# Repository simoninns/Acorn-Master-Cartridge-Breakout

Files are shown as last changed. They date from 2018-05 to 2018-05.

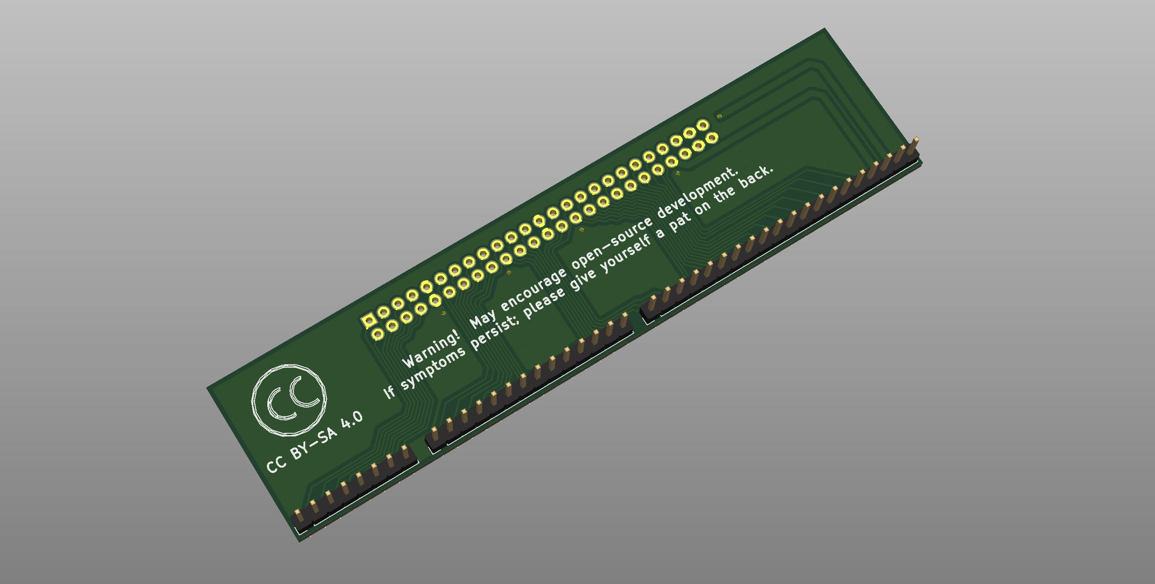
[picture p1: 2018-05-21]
Breadboard/Breadboard Header - bottom.jpg

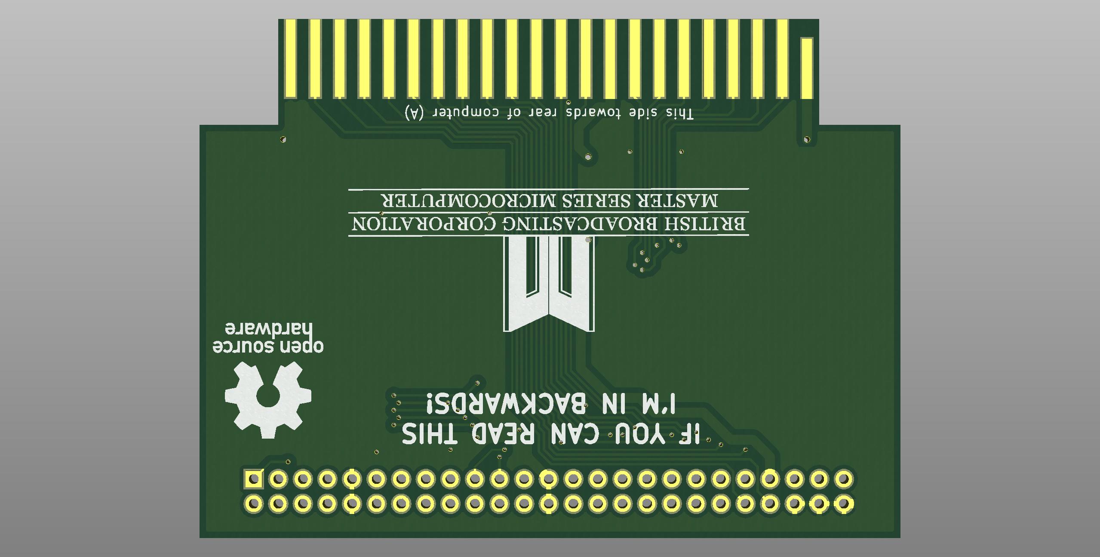
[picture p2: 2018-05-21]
Cartridge/Cartridge Header - bottom.jpg

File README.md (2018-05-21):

# Acorn-Master-Cartridge-Breakout
A breakout adapter for the Acorn Master 128 cartridge interface for connection to a breadboard

## Synopsis

This card is designed to allow connection between an Acorn BBC Master's cartridge interface and an electronics breadboard.  To save production cost the board is designed as two PCBs.  The cartridge header should be produced with a gold finish due to the edge connector (this is not required for the breadboard header).

## Motivation

Prototyping new Acorn BBC Master hardware.

## Author

The Acorn Master Cartridge Breakout board was designed by Simon Inns.

## License

This project is released under a Creative Commons Attribution-ShareAlike 4.0 International (CC BY-SA 4.0) licence.

You are free to:

Share — copy and redistribute the material in any medium or format
Adapt — remix, transform, and build upon the material
for any purpose, even commercially.

This license is acceptable for Free Cultural Works.

The licensor cannot revoke these freedoms as long as you follow the license terms.

Under the following terms:

Attribution — You must give appropriate credit, provide a link to the license,
and indicate if changes were made. You may do so in any reasonable manner, but
not in any way that suggests the licensor endorses you or your use.

ShareAlike — If you remix, transform, or build upon the material, you must
distribute your contributions under the same license as the original.

No additional restrictions — You may not apply legal terms or technological
measures that legally restrict others from doing anything the license permits.

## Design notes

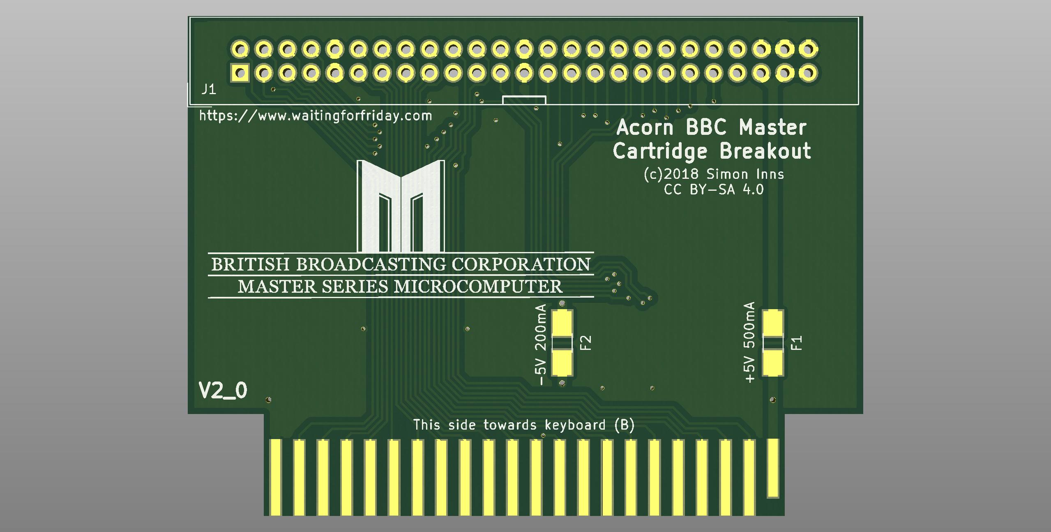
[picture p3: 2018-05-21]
Cartridge/Cartridge Header - top.jpg

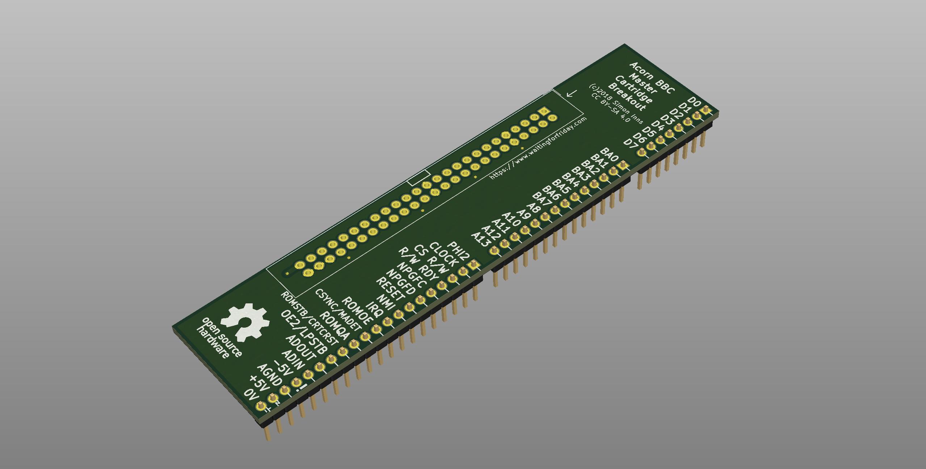
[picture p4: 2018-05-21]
Breadboard/Breadboard Header - top.jpg

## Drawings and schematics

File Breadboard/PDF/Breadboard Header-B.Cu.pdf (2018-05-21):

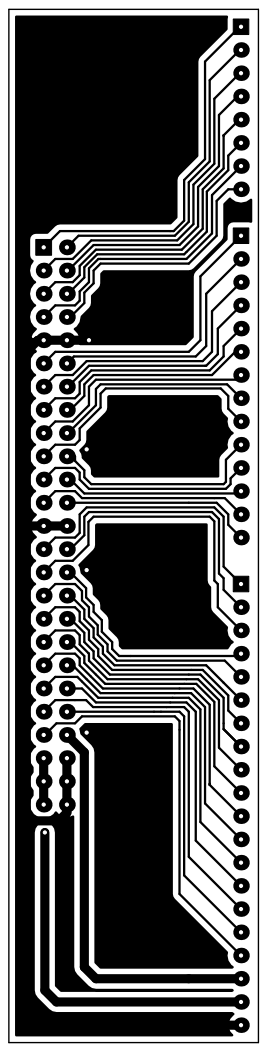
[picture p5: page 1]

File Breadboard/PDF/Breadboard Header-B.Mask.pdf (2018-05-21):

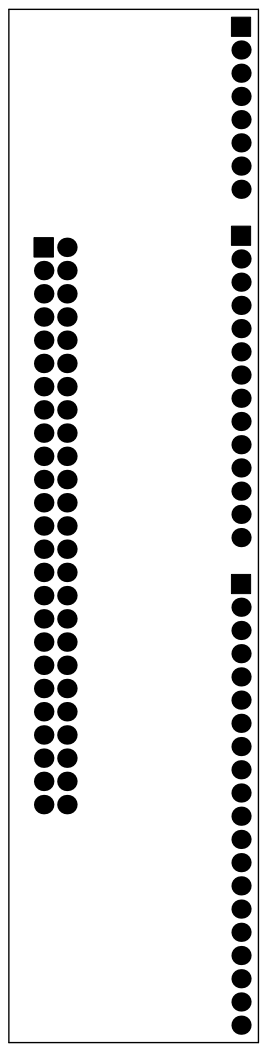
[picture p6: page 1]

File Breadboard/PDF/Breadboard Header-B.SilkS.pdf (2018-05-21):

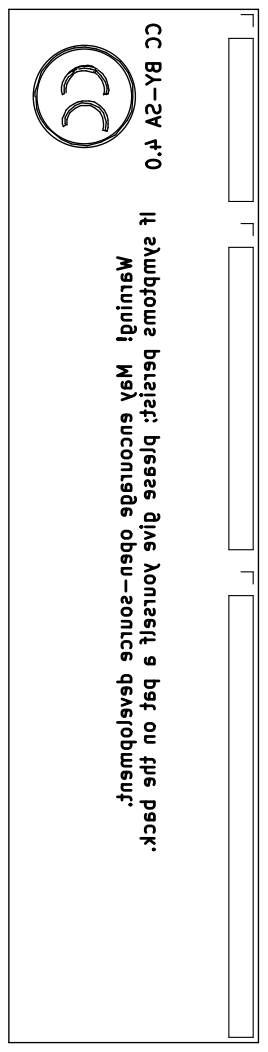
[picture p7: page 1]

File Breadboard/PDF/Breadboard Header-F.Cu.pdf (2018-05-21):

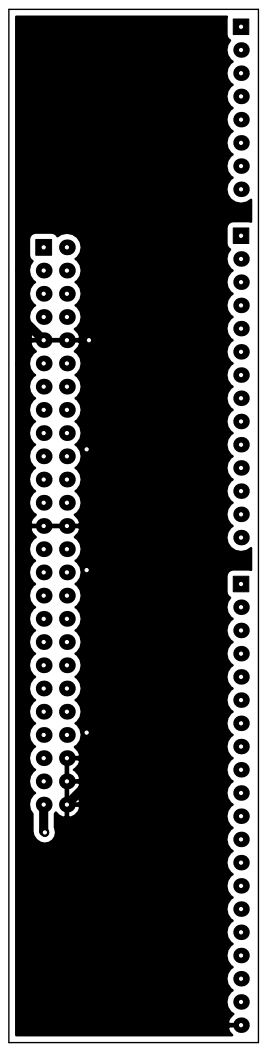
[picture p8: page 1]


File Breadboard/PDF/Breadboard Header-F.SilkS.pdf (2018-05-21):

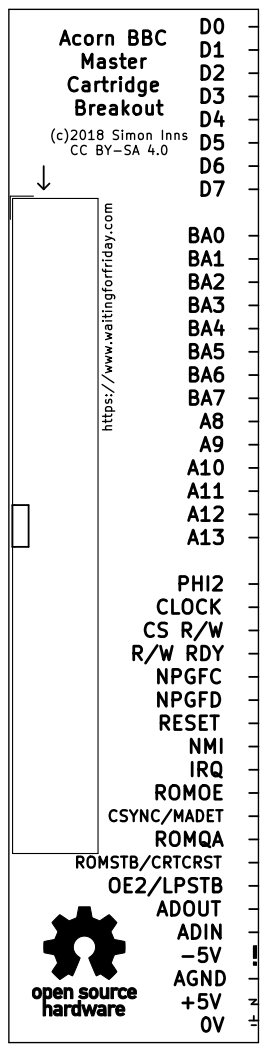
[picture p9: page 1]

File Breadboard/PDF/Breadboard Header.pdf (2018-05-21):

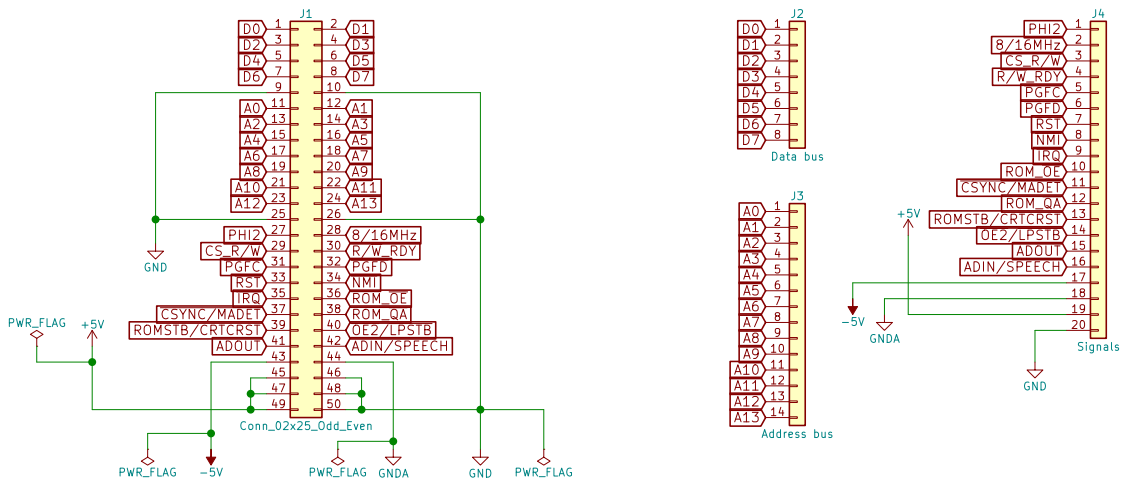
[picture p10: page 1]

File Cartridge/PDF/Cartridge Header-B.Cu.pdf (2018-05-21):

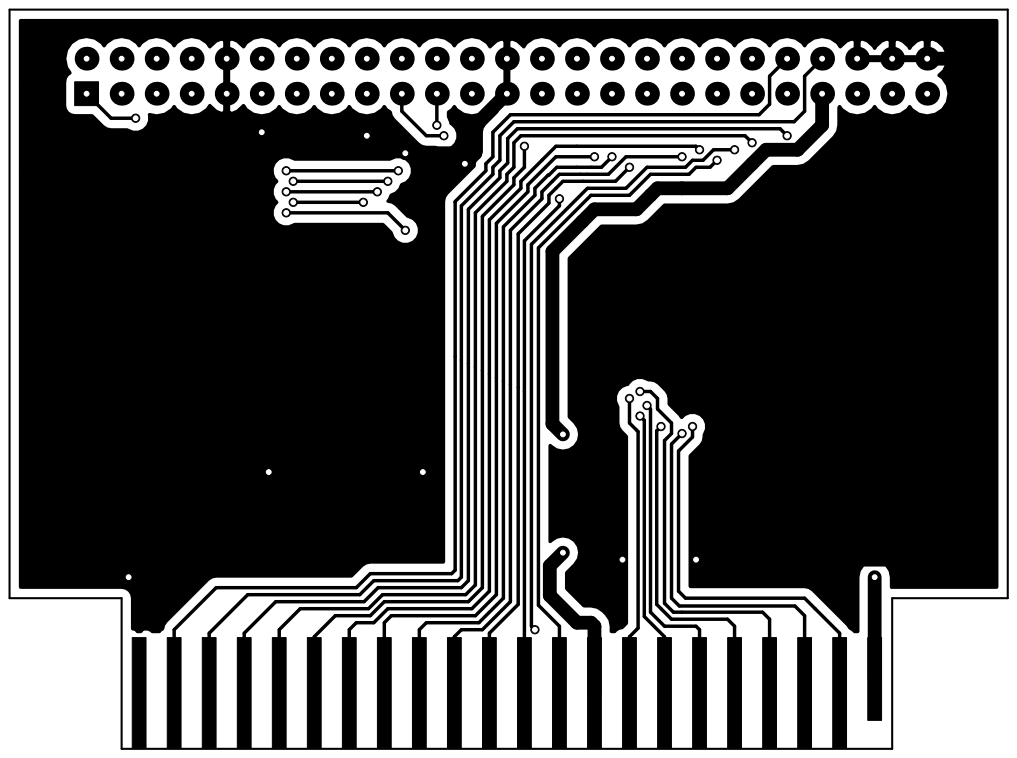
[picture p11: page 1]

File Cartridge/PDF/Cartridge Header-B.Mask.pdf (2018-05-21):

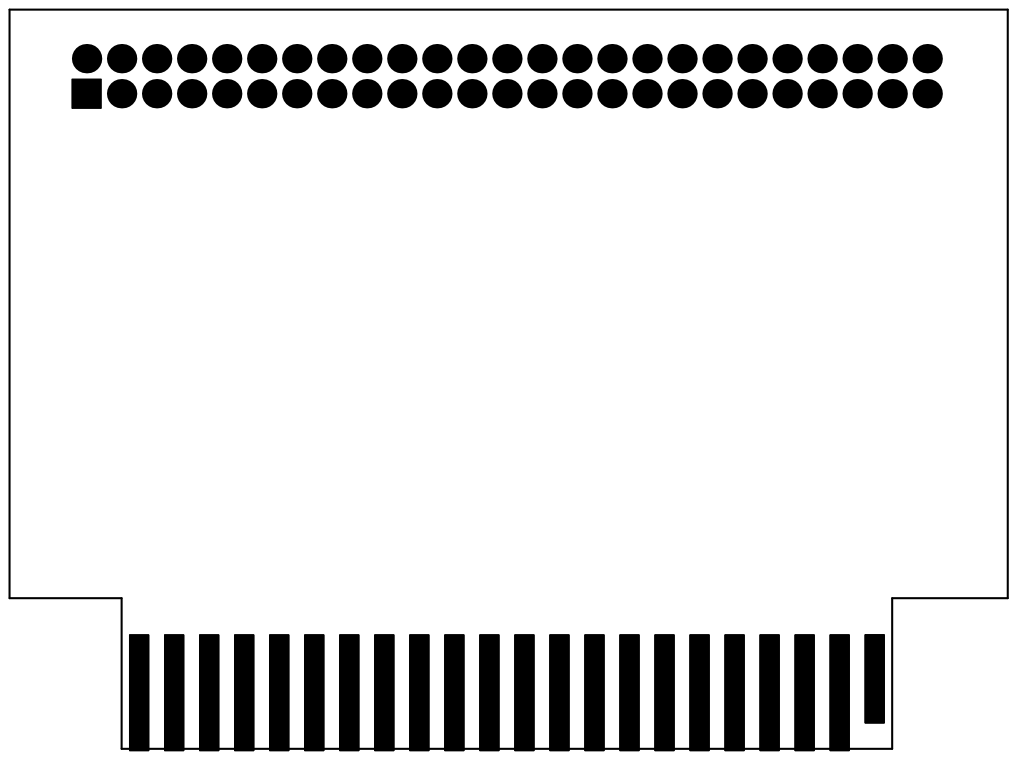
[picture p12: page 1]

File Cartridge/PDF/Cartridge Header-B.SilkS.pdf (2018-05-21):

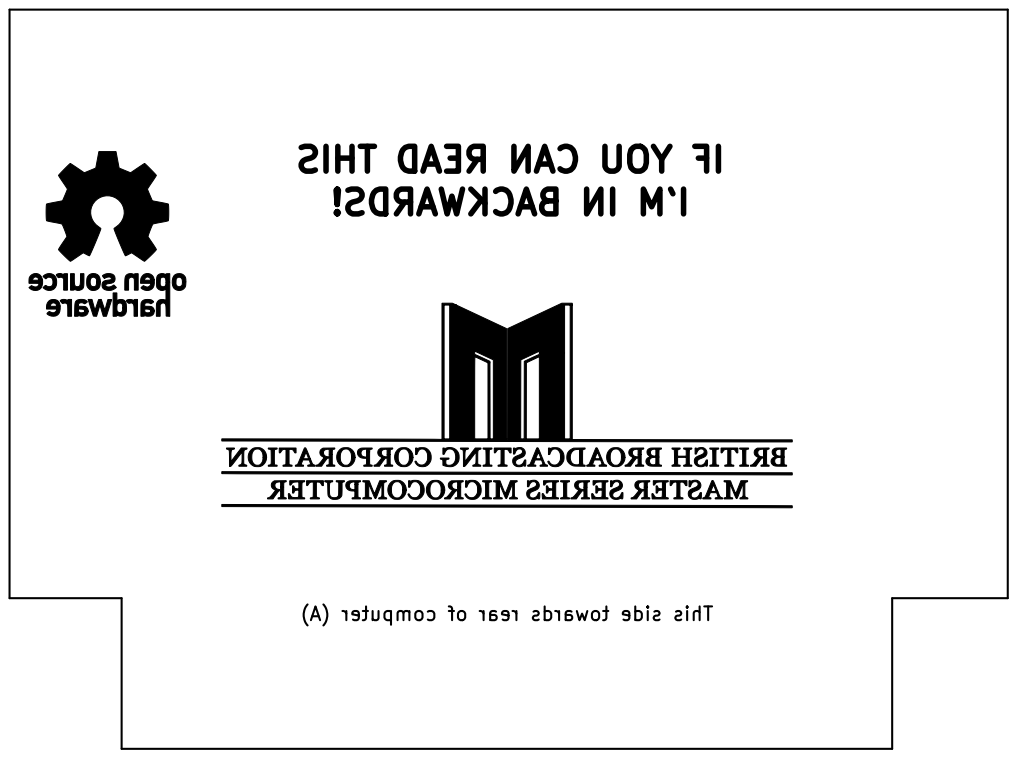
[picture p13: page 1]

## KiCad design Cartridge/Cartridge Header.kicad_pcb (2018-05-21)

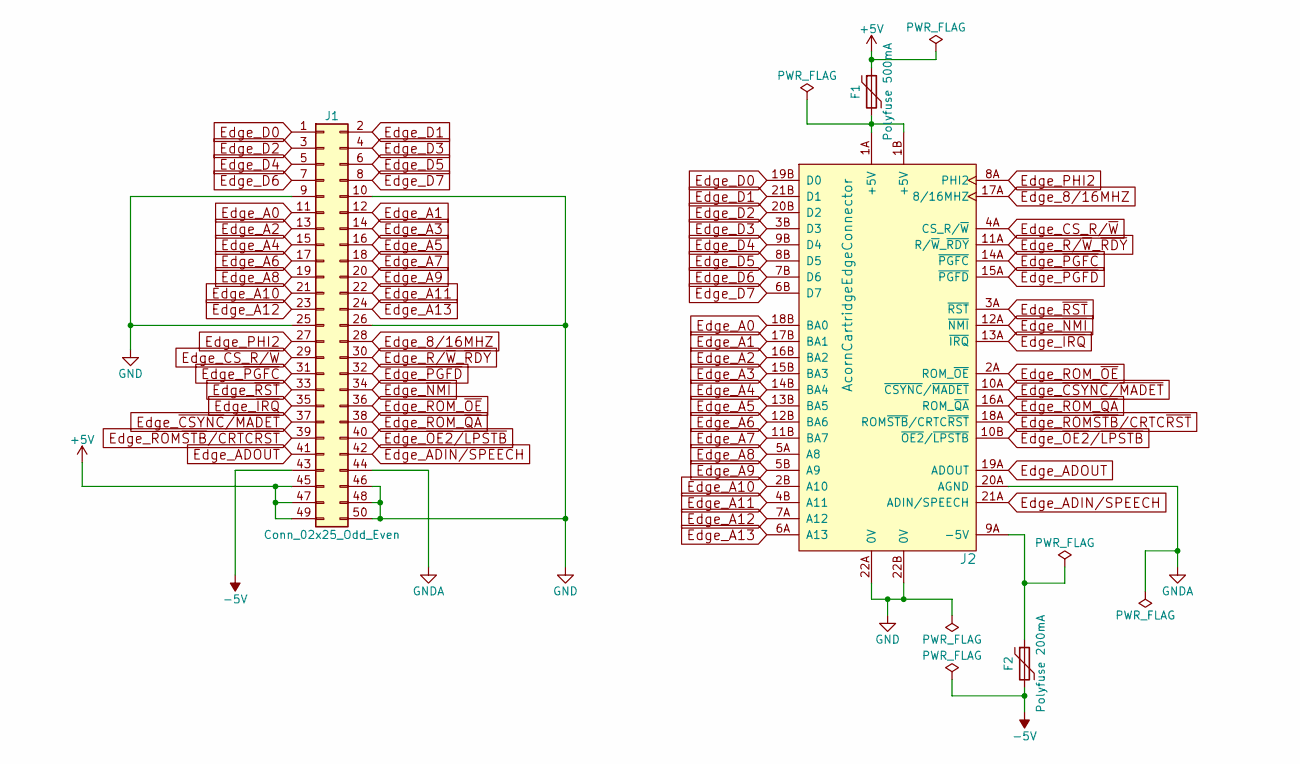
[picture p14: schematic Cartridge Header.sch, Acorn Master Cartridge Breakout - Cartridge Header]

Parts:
F1: Polyfuse 500mA; Fuse_SMD1206_HandSoldering
F2: Polyfuse 200mA; Fuse_SMD1206_HandSoldering
J1: Conn_02x25_Odd_Even; IDC-Header_2x25_Pitch2.54mm_Straight
J2: AcornCartridgeEdgeConnector; Acorn_Cartridge

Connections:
+5V: F1.1, J1.45, J1.47, J1.49
-5V: F2.2, J1.43
Edge_8/16MHZ: J1.28, J2.17A (8/16MHZ)
Edge_A0: J1.11, J2.18B (BA0)
Edge_A1: J1.12, J2.17B (BA1)
Edge_A2: J1.13, J2.16B (BA2)
Edge_A3: J1.14, J2.15B (BA3)
Edge_A4: J1.15, J2.14B (BA4)
Edge_A5: J1.16, J2.13B (BA5)
Edge_A6: J1.17, J2.12B (BA6)
Edge_A7: J1.18, J2.11B (BA7)
Edge_A8: J1.19, J2.5A (A8)
Edge_A9: J1.20, J2.5B (A9)
Edge_A10: J1.21, J2.2B (A10)
Edge_A11: J1.22, J2.4B (A11)
Edge_A12: J1.23, J2.7A (A12)
Edge_A13: J1.24, J2.6A (A13)
Edge_ADIN/SPEECH: J1.42, J2.21A (ADIN/SPEECH)
Edge_ADOUT: J1.41, J2.19A (ADOUT)
Edge_CS_R/~W: J1.29, J2.4A (CS_R/~W)
Edge_D0: J1.1, J2.19B (D0)
Edge_D1: J1.2, J2.21B (D1)
Edge_D2: J1.3, J2.20B (D2)
Edge_D3: J1.4, J2.3B (D3)
Edge_D4: J1.5, J2.9B (D4)
Edge_D5: J1.6, J2.8B (D5)
Edge_D6: J1.7, J2.7B (D6)
Edge_D7: J1.8, J2.6B (D7)
Edge_PHI2: J1.27, J2.8A (PHI2)
Edge_R/~W~_~RDY: J1.30, J2.11A (R/~W~_~RDY)
Edge_ROM_~OE: J1.36, J2.2A (ROM_~OE)
Edge_ROM_~QA: J1.38, J2.16A (ROM_~QA)
Edge_ROM~STB~/CRTC~RST: J1.39, J2.18A (ROM~STB~/CRTC~RST)
Edge_~CSYNC~/~MADET: J1.37, J2.10A (~CSYNC~/~MADET)
Edge_~IRQ: J1.35, J2.13A (~IRQ)
Edge_~NMI: J1.34, J2.12A (~NMI)
Edge_~OE2~/~LPSTB: J1.40, J2.10B (~OE2~/~LPSTB)
Edge_~PGFC: J1.31, J2.14A (~PGFC)
Edge_~PGFD: J1.32, J2.15A (~PGFD)
Edge_~RST: J1.33, J2.3A (~RST)
GND: J1.9, J1.10, J1.25, J1.26, J1.46, J1.48, J1.50, J2.22A (0V), J2.22B (0V)
GNDA: J1.44, J2.20A (AGND)
unnamed: F1.2, J2.1A (+5V), J2.1B (+5V)
unnamed: F2.1, J2.9A (-5V)

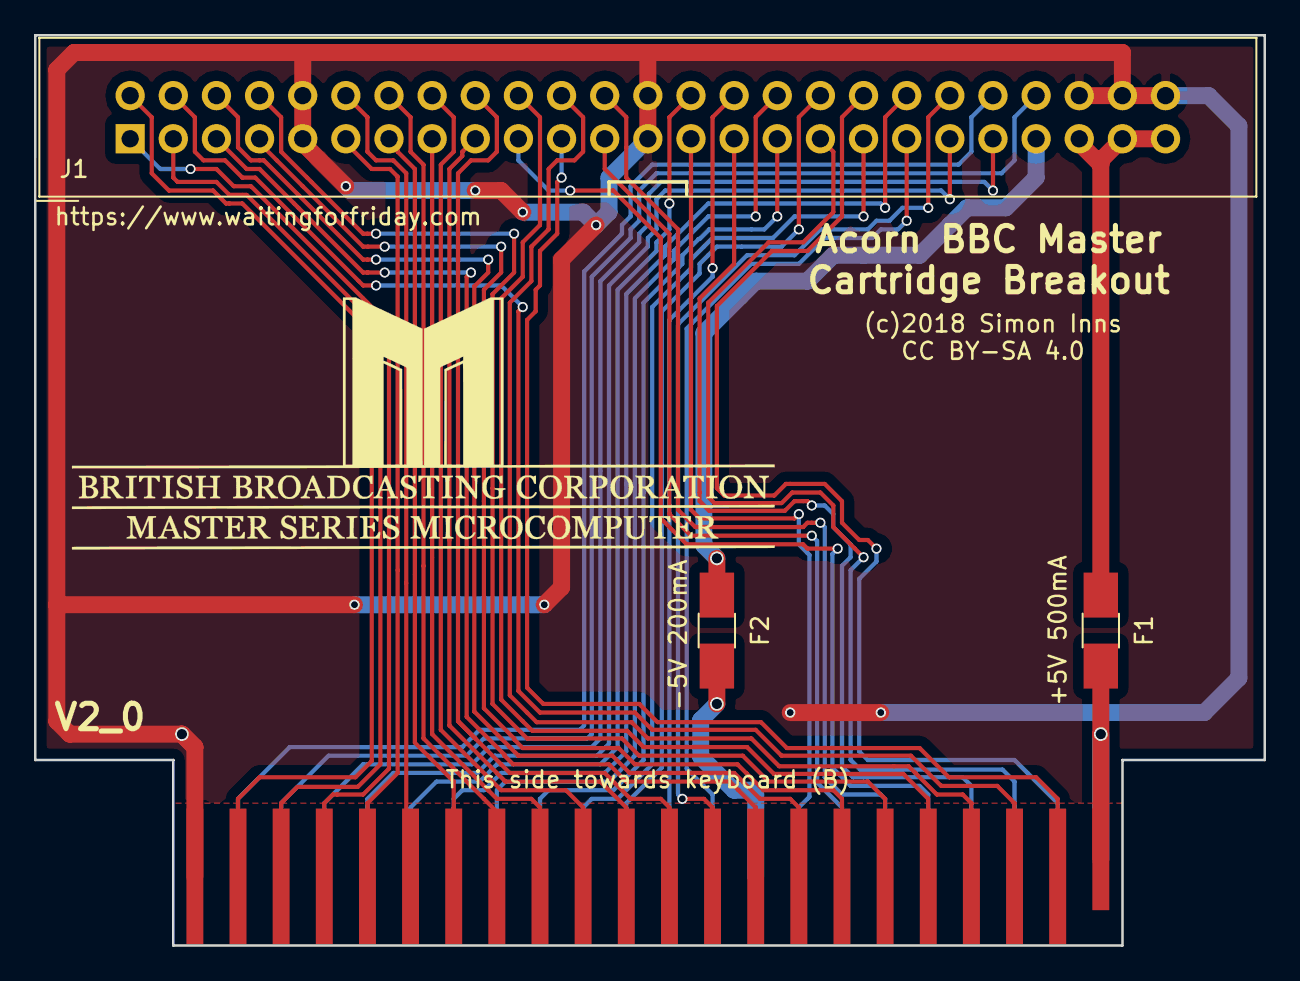
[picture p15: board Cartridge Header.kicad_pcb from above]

Board: 2 copper layers, 72.4 x 53.6 mm, 4 parts (0 on the bottom side), 44 nets.

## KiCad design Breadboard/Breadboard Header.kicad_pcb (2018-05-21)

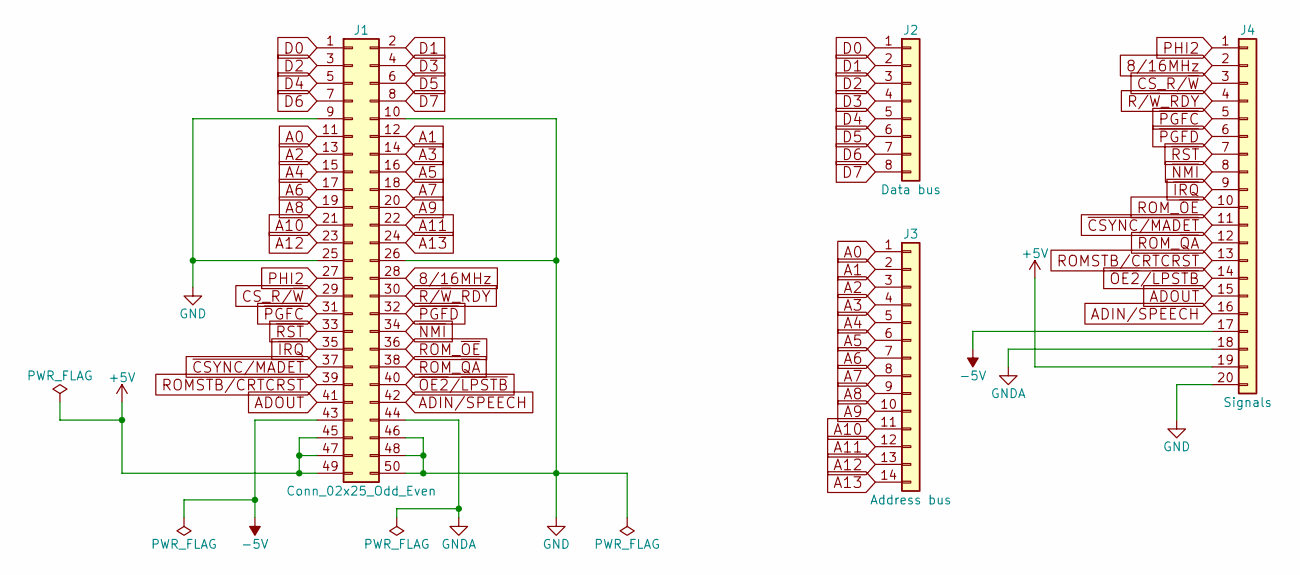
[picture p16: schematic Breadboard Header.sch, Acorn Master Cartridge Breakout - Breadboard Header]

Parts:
J1: Conn_02x25_Odd_Even; IDC-Header_2x25_Pitch2.54mm_Straight
J2: Data bus; Pin_Header_Straight_1x08_Pitch2.54mm
J3: Address bus; Pin_Header_Straight_1x14_Pitch2.54mm
J4: Signals; Pin_Header_Straight_1x20_Pitch2.54mm

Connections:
8/16MHz: J1.28, J4.2
+5V: J1.45, J1.47, J1.49, J4.19
-5V: J1.43, J4.17
A0: J1.11, J3.1
A1: J1.12, J3.2
A2: J1.13, J3.3
A3: J1.14, J3.4
A4: J1.15, J3.5
A5: J1.16, J3.6
A6: J1.17, J3.7
A7: J1.18, J3.8
A8: J1.19, J3.9
A9: J1.20, J3.10
A10: J1.21, J3.11
A11: J1.22, J3.12
A12: J1.23, J3.13
A13: J1.24, J3.14
ADIN/SPEECH: J1.42, J4.16
ADOUT: J1.41, J4.15
CS_R/~W: J1.29, J4.3
D0: J1.1, J2.1
D1: J1.2, J2.2
D2: J1.3, J2.3
D3: J1.4, J2.4
D4: J1.5, J2.5
D5: J1.6, J2.6
D6: J1.7, J2.7
D7: J1.8, J2.8
GND: J1.9, J1.10, J1.25, J1.26, J1.46, J1.48, J1.50, J4.20
GNDA: J1.44, J4.18
PHI2: J1.27, J4.1
R/~W~_RDY: J1.30, J4.4
ROMSTB/CRTCRST: J1.39, J4.13
ROM_~OE: J1.36, J4.10
ROM_~QA: J1.38, J4.12
~CSYNC/MADET: J1.37, J4.11
~IRQ: J1.35, J4.9
~NMI: J1.34, J4.8
~OE2~/~LPSTB: J1.40, J4.14
~PGFC: J1.31, J4.5
~PGFD: J1.32, J4.6
~RST: J1.33, J4.7

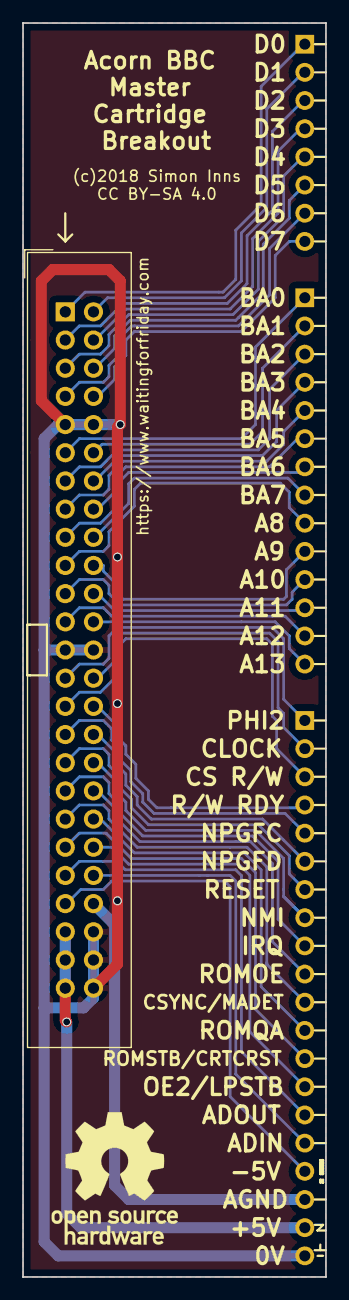
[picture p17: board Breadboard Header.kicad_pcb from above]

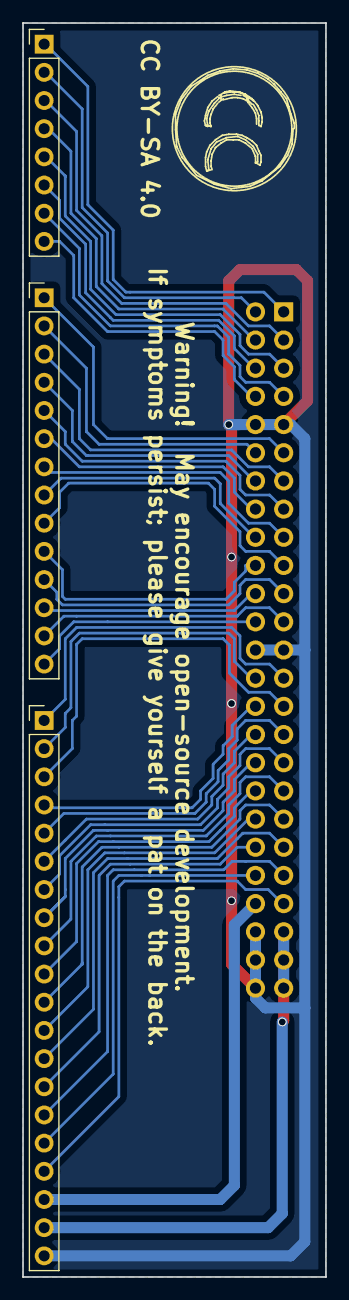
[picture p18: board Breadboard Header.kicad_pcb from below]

Board: 2 copper layers, 27.3 x 113.0 mm, 5 parts (4 on the bottom side), 42 nets.

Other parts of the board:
CC BY-SA 4.0: Symbol_CreativeCommons_SilkScreenTop_Type2_Big

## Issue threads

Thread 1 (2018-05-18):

Edge connector surfaces are reflected

simoninns, 2018-05-18:
The edge connector pins are reflected in the current design and the component symbol is therefore incorrect.  This causes all connections to be incorrectly routed.  The board requires re-routing.

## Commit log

2018-05-06 Initial commit of design
    [Acorn Master Cartridge Breakout.kicad_pcb, Acorn Master Cartridge Breakout.sch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]
2018-05-06 Corrected back PCB image
2018-05-06 Updated with addition edge-cuts to allow the panel to be scored
    [Acorn Master Cartridge Breakout.kicad_pcb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]
2018-05-06 Remade as a single panel with silkscreen cut marks
    [Acorn Master Cartridge Breakout.kicad_pcb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]
2018-05-06 Updated board image jpegs
2018-05-06 Moved outline and added V-scores for multiple boards
    Note: KiCAD's 3D renderer does not correctly trace the edge-cuts
    [Acorn Master Cartridge Breakout.kicad_pcb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]
2018-05-07 New design using mouse-bites and including poly-fuses
    [Acorn Master Cartridge Breakout.kicad_pcb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]
2018-05-07 Added missing solder mask Gerbers
    [Acorn Master Cartridge Breakout-B.Cu.gbr, Acorn Master Cartridge Breakout-B.Mask.gbr, Acorn Master Cartridge Breakout-B.SilkS.gbr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]
2018-05-19 New PCB design to fix #1
    [Acorn Master Cartridge Breakout-B.Cu.gbr, Acorn Master Cartridge Breakout-B.Mask.gbr, Acorn Master Cartridge Breakout-B.SilkS.gbr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]
2018-05-21 Modified design to provide a continuous external edge cut profile
    [Acorn Master Cartridge Breakout-B.Cu.gbr, Acorn Master Cartridge Breakout-B.Mask.gbr, Acorn Master Cartridge Breakout-B.SilkS.gbr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]
2018-05-21 Updated PCB images
2018-05-21 Split into two redesigned PCBs
    Seems impossible to get a PCB house to understand that a 10x10 PCB is a single PCB; due to this the breakout adapter has been redesigned as two PCBs interconnected by a 50 way ribbon cable (so you can use an old SCSI lead).
    [Acorn Master Cartridge Breakout-B.Cu.gbr, Acorn Master Cartridge Breakout-B.Mask.gbr, Acorn Master Cartridge Breakout-B.SilkS.gbr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]
2018-05-21 Removed unnecessary files
    [Acorn Master Cartridge Breakout-B.Cu.gbr, Acorn Master Cartridge Breakout-B.Mask.gbr, Acorn Master Cartridge Breakout-B.SilkS.gbr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]

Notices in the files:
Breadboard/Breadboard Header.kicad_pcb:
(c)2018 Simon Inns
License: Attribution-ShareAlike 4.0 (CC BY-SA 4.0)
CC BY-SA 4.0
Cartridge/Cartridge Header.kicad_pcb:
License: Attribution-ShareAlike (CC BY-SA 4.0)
